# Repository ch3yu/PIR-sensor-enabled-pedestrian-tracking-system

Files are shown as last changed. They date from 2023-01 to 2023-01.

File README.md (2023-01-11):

# PIR-sensor-enabled-pedestrian-tracking-system

### **:closed_book:Introduction**

Passive infrared (PIR) sensors are motion sensors that detect IR stimuli emitted by heating bodies and convert them into electrical outputs. They are used in a variety of applications, such as home automation, surveillance systems, and human trajectory analysis since they are low-cost, reliable and anonymous compared to other sensors like camera and Bluetooth tags, which are relatively expensive and privacy-invasive. 

PIR sensors are categorized into digital and analog sensors, and they both have their advantages and disadvantages.  Digital PIR sensors are the more common option that outputs 1 when motions are detected and 0 otherwise. A considerable number of applications that leverage their binary outputs since they require less effort to process and off-the-shelf digital PIR sensors are easy to access due to its prevalence. However, the digital characteristics also narrow the information availability to users – digital PIR sensors can reflect nothing more than the presence of motions. Whereas its analog counterpart can not only sense motions, but also provide direction, velocity, and distance of pedestrians relative to the sensor by giving different outputs, which requires multiple digital PIR sensors to work synergistically to collect the same information. As informative as analog PIR sensors can be, they require additional amplification since the raw analog outputs are not prominent enough to be observed and processed directly by microcontrollers. Despite the implication of an additional amplifier, we still prefer analog PIR sensors since they are not only more informative, but they are also more energy-efficient in contrast to the digital counterpart when requiring the same capabilities.

To enable more people to benefit from analog PIR sensors, we designed a sensing node that pivots around an analog PIR sensor and included a GPS, SD card module, Arduino UNO, a divided cone, and a power supply system. In the sensing node, we have a plastic circuit board (PCB) that harbors the amplifier for the analog output, SD card module for data storage, and GPS capability to document information captured by the PIR sensor chronologically. The PCB also serves as a shield that sits atop an Arduino UNO so that users can expand the functionalities of the PCB of their own accord. Additionally, we also devised a cone with a divider that increases the sensitivity of the sensor. All components reside in a water-proof enclosure and are powered by a battery, which is sustainably charged by a solar panel.

In this GitHub page, we have a sensor node building manual, bill of materials, design files, and code in different branches. Please refer to the index section for further information for the purposes of each file.

### **:scroll:Index**

- Pedestrian tracking system sensing node assembling manual: A step-by-step instruction that goes through the process of building a sensing node pivoting around an analog PIR sensor.
- Bill of materials: A list that includes all the materials needed to build a sensing node.
- Design files:
  - Pedestrian tracking system: A compressed folder that contains the Gerber files for the Arduino shield.
  - Cone and tube stl files: The stl files that can be sent to a 3D printing manufacturer to print out the cone and the tube.
- pedestrian_tracking_system_3: The code that operates to document direction of travel of passengers.

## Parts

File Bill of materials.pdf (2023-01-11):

Category | Item | Part Number | Quantity | Vendor | Note
Electronics | PIR sensor | D203B | 1 | Ebay
| SD card module | Daier 1.29 | 1 | Amazon
| SD card | B087JCL881 | 1 | Amazon
| GPS receiver | GPS-13670 | 1 | Sparkfun
| GPS jumper wires | PRT-10361 | 1 | Sparkfun
| Arduino UNO | A000066 | 1 | Amazon
| Op-amp | LF412ACN/NOPB | 2 | Digikey
| Resistor - 10k | CF14JT10K0TR-ND | 3 | Digikey
| Resistor - 100k | CF18JT100KTR-ND | 1 | Digikey
| Resistor - 1M | VR68J1.0MCT-ND | 3 | Digikey
| Resistor - 3.3M | CF14JT3M30TR-ND | 1 | Digikey
| Capacitor - 0.1u | 493-12784-1-ND | 2 | Digikey
| Capacitor - 10u | 493-7383-1-ND | 3 | Digikey
| Male header | PBC36SADN | 1 | Digikey
| Two-position female header | PPTC021LFBN-RC | 1 | Digikey
| Three-position female header | PPPC031LFBN-RC | 1 | Digikey
| Two-position terminal block | B08B3JP9QZ | 1 | Amazon
| Three-position terminal block | B082QZ8Q3X | 1 | Amazon
Enclosure | Waterproof box | WQ-55-02 | 1 | Polycase
| Pole mount kit for box | PK-083 | 1 | Polycase
| Screws | SCREWS-032-50 | 1 | Polycase
Power Supply | Battery | PS-1280-F1 | 1 | TNR technical
| Solar controller | SS-6L-12V | 1 | Morning Star
| Female connection receptacle | 298-10278-ND | 2 | Digikey | Used to connect the 12 AWG chord to the terminals of the battery
| 12 AWG chords | B074GG48F2 | 3 | Amazon
| Solar panel | HY010-12M | 1 | Acopower
| Pole mount kit for solar panel | SLB-0120 | 1 | Solarland
| Connection receptacle | 889-1000-ND | 1 | Digikey | Used to create water-proof connection for the solar panel and the enclosure
| Connection plug | 889-1012-ND | 1 | Digikey
| Nickel crimp | 889-1049-1-ND | 1 | Digikey
| Cable | 1897CSL002-ND | 1 | Digikey
| Cable gland | AIO-CSM12-ND | 1 | Digikey
Miscellaneous | Jumper wires | 1988-1169-ND | 5 | Digikey
| Zip ties | B08TBM621K | 1 | Amazon
| Electrical tape | 13717044 | 1 | Target
| Gorilla super glue | 75575255 | 1 | Target
| Solder machine | MX 500S | 1 | Metcal
| Solder wire | 468-480 | 1 | Jensen
| Drill | B09SN6Y6TS | 1 | Amazon | The drill bit has 0.5" diameter

Note: This bill of materials is listed for one sensing node.

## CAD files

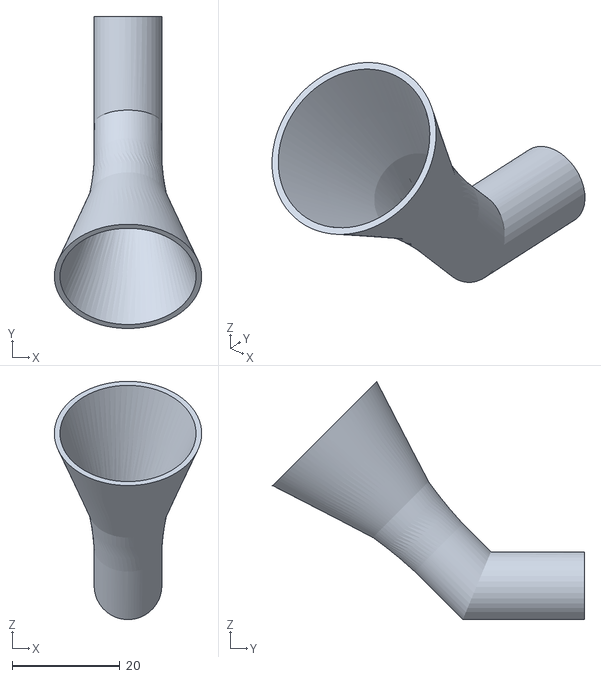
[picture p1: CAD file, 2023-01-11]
Design files/Tube.STL
27.4 x 58.0 x 44.3

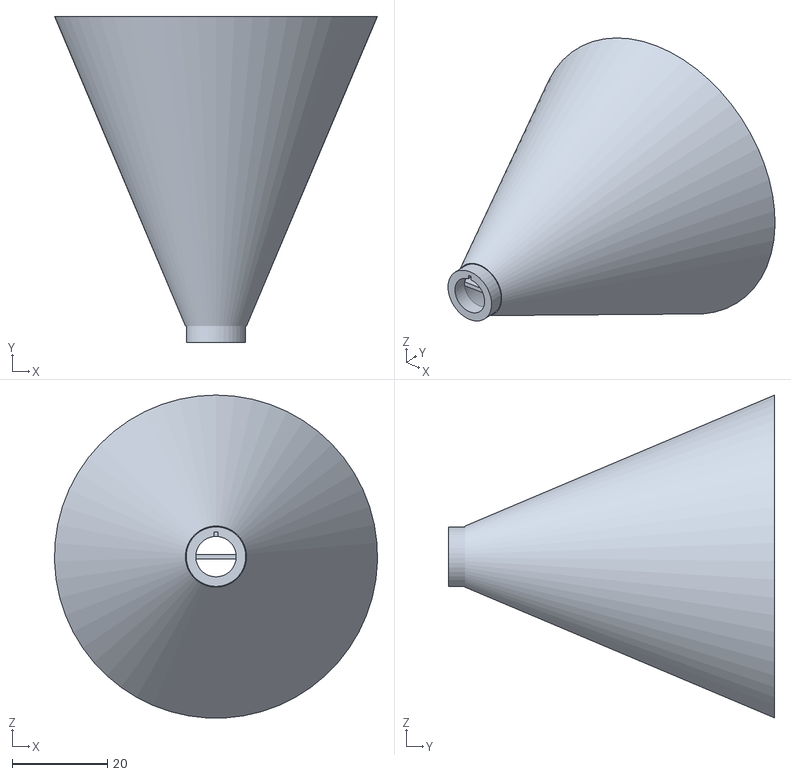
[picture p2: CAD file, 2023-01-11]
Design files/Cone.STL
67.8 x 68.5 x 67.8

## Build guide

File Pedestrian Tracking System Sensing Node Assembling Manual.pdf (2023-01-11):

# Pedestrian Tracking System Sensing Node Assembling Manual

## Author: Cheyu Lin

## Contact: cheyul@andrew.cmu.edu

Index

Introduction

Passive infrared (PIR) sensors are motion sensors that detect IR stimuli emitted by heating bodies and convert them into electrical outputs. They are used in a variety of applications, such as home automation, surveillance systems, and human trajectory analysis since they are low-cost, reliable and anonymous compared to other sensors like camera and Bluetooth tags, which are relatively expensive and privacy-invasive.

PIR sensors are categorized into digital and analog sensors, and they both have their advantages and disadvantages. Digital PIR sensors are the more common option that outputs 1 when motions are detected and 0 otherwise. A considerable number of applications leverage their binary nature since binary outputs require less effort to process and off-the-shelf digital PIR sensors are easy to access due to its prevalence. However, the digital characteristics also narrow the information availablility to users – digital PIR sensors can reflect nothing more than the presence of motions. Whereas its analog counterpart can not only sense motions, but also provide direction, velocity, and distance of pedestrians relative to the sensor by giving different outputs, which requires multiple digital PIR sensors to work synergistically to collect the same information. As informative as analog PIR sensors can be, they require additional amplification since the raw analog outputs are not prominent enough to be observed and processed directly by microcontrollers. Despite the implication of an additional amplifier, we still prefer analog PIR sensors since they are not only more informative, but they are also more energy-efficient in contrast to the digital counterpart when requiring the same capabilities.

To enable more people to benefit from analog PIR sensors, we designed a sensing node that pivots around an analog PIR sensor and included a GPS, SD card module, Arduino UNO, a divided cone, and a power supply system. In the sensing node, we have a plastic circuit board (PCB) that harbors the amplifier for the analog output, SD card module for data storage, and GPS capability to document information captured by the PIR sensor chronologically. The PCB also serves as a shield that sits atop an Arduino UNO so that users can expand the functionalities of the sensing node of their own accord. Additionally, we also devised a divided cone that increases the sensitivity of the sensor. All components reside in a water-proof enclosure and are powered by a battery, which is sustainably charged by a solar panel.

In this manual, we provide step-by-step instructions pictorially to construct the sensing node, which entailstools required to build the sensing node, the process of soldering components onto the PCB, assembling the cone, creating water-proof connections that are exposed, and putting everything together. To download design files for the PCB and the cone, code, and bill of materials, please consult the GitHub page.

Tools Required to Build the Sensing Node

Fig. 1 and 2 show all the tools needed to assemble the sensing node.

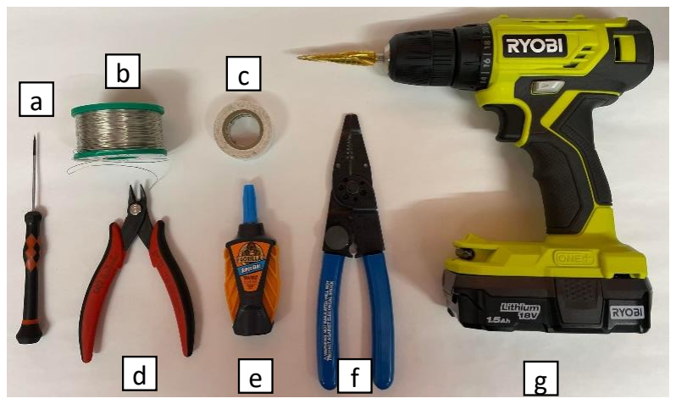
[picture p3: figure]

Fig. 1. (a) Flat-head screwdriver (b) solder wire
(c) electrical tape (d) wire cutter (e) super glue
(f) wire strip (g) driller

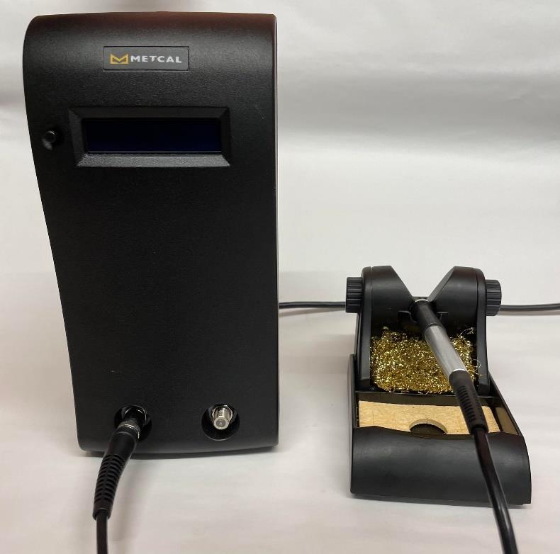
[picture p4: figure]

Fig. 2. Solder station and solder iron

PCB Schematic

In this section, we have the schematic of the Arduino shield that is comprised of external power supply, Arduino power supply, GPS and SD card module connections, and PIR signal amplifier in Fig. 2. The external power supply is connected to a 12-V battery to power Arduino, which subsequently powers the operation of the rest of the circuit through the 5-V pin in the Arduino power supply. GPS and SD card module are connected to the shield through “JP” labelled solder pads. As for the PIR signal amplifier, it processes the raw PIR signal by sending the signal through a non-inverting and an inverting band-pass filter, made up of operational amplifiers, resistors, and capacitors, and feeding the output to Arduino’s analog pin A1. As a side note, “JP” labelled solder pads named “Arduino spare pins” are for adding external components according to user’s needs. For instance, if an LED light is required, one can connect it to pin 5 in JP6, and control it through Arduino’s digital pin 5.

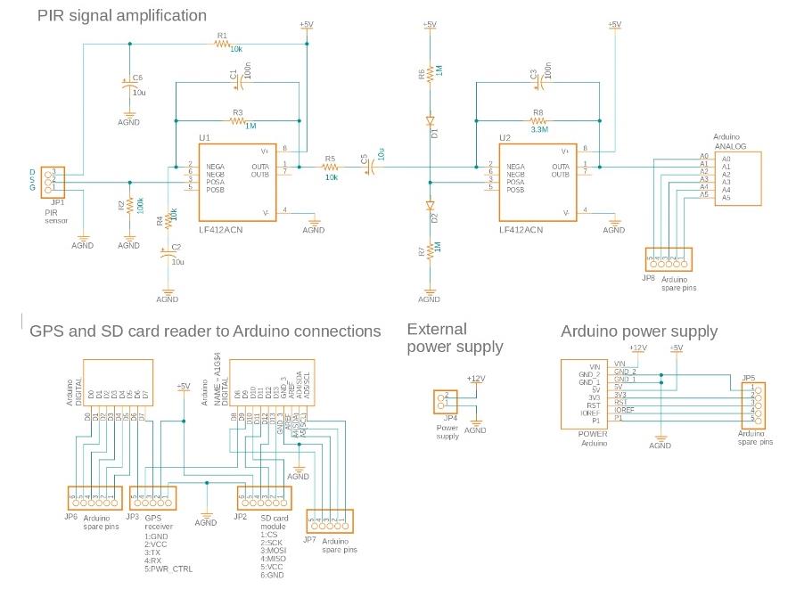
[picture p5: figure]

Fig. 2. Schematic of the Arduino shield that includes amplifier for raw PIR signal, GPS, and SD card module.

Soldering Arduino Shield

1. Download Gerber files from GitHub page under main -> Design files -> Pedestrian tracking system.zip. Print the PCB from the PCB factory of user’s preference.
2. Purchase components listed in the bill of materials (also accessible in GitHub page). If user has your own preferences, please ensure that components bought would line up with solder pads on the PCB.
3. Identify the front and back sides in Fig. 3 before soldering since some components belong to the front side and others belong the back side.

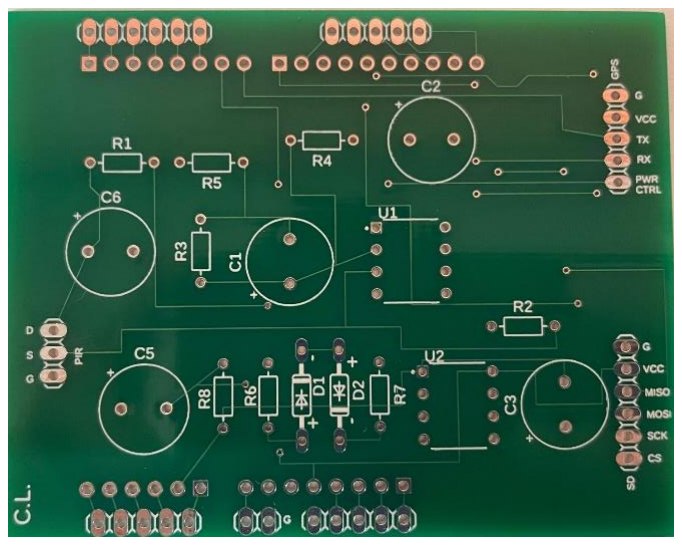
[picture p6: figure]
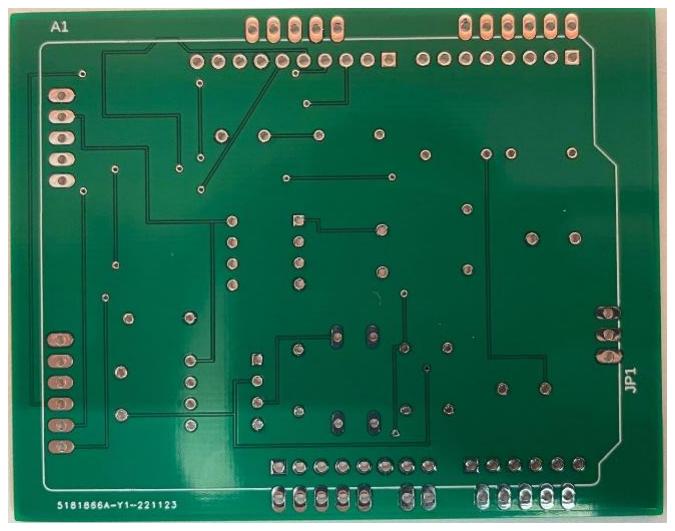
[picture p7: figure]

(a) (b)
Fig. 3. (a) The front side of the PCB has resistors, capacitors, diodes, and op-amps labelled as “R”, “C”, “D”, and “U” respectively. The “+” signs indicate positive polarity. (b) The back side of the PCB.
4. Solder the SD card module onto the back of the PCB by connecting module’s pins to their corresponding places as shown in Fig. 4.
5. Solder the short end of male headers onto the front side of the PCB as in Fig. 5. One tip is to insert the long end of the headers into an Arduino and place the PCB on top while soldering to ensure headers are not lopsided. A caveat is that the long end of headers must be long enough to leave a clearance when fitting the PCB onto Arduino. See Fig 13 for visual explanation.
6. Solder op-amps onto the front side of the PCB with the dented pit on the op-amp aligning the white dot on the PCB as shown in Fig. 6.

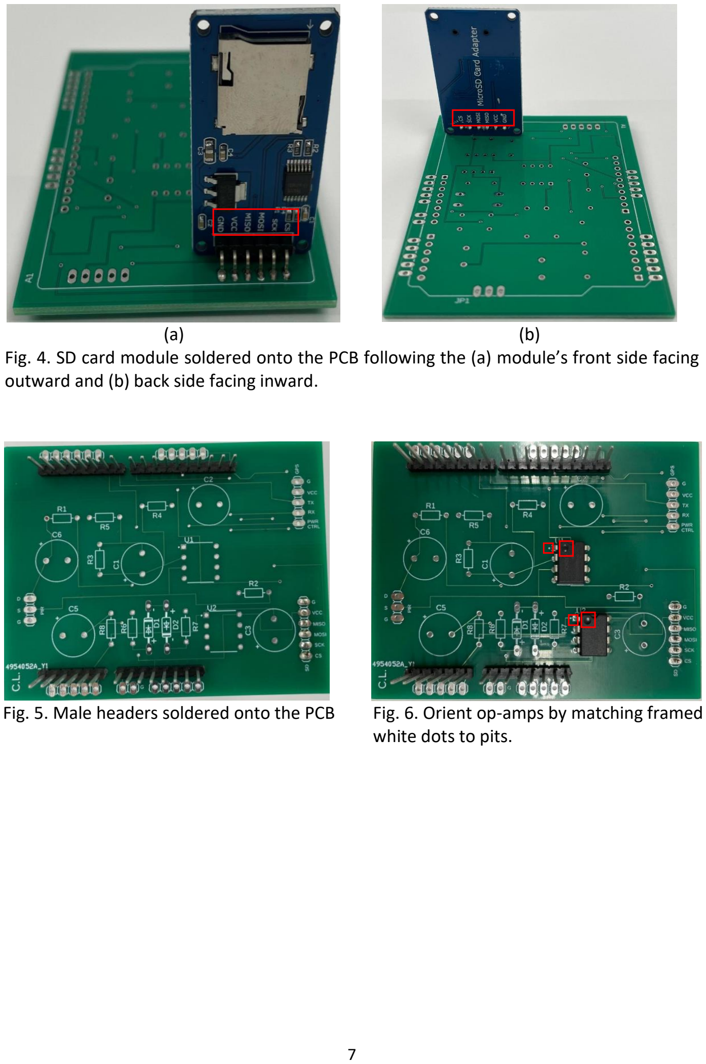
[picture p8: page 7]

(a) (b)
Fig. 4. SD card module soldered onto the PCB following the (a) module’s front side facing outward and (b) back side facing inward.

Fig. 5. Male headers soldered onto the PCB Fig. 6. Orient op-amps by matching framed white dots to pits.

7. Resistors are on the back side of the PCB. Solder 10k resistors to R1, R4, and R5; 100k to R2; 1M to R3, R6, and R7; 3.3M to R8. See Fig. 3 and 7 for reference.

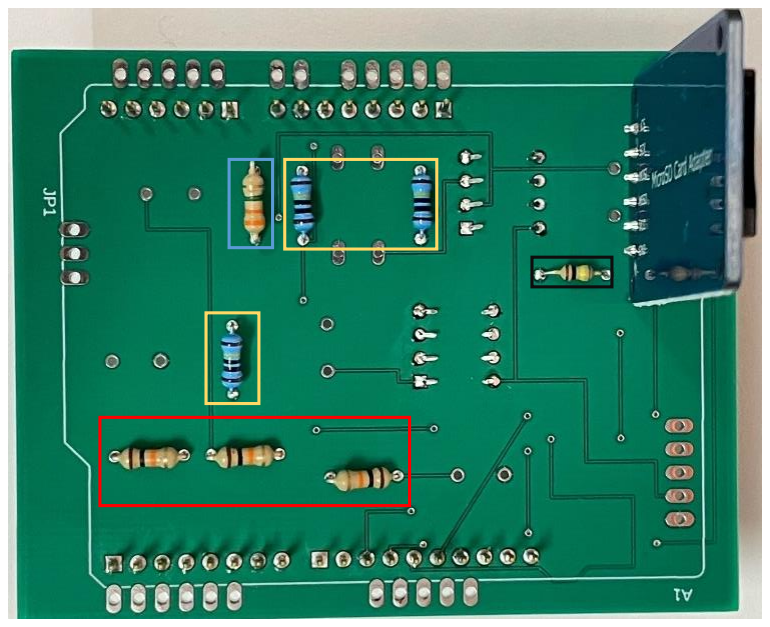
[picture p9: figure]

Fig. 7. Resistors are framed with different colors to indicate different resistances. 10k resistors are red. 100k resistor is black. 1M resistors are boxed yellow. 3.3M resistor is boxed blue.

8. Connect polarized capacitors on the back of the PCB with the white stripe on the capacitor lining up with the negative sign on the PCB. Please refer to Fig. 3 and 8 to identify the polarities of capacitors and the corresponding solder pads on the PCB.

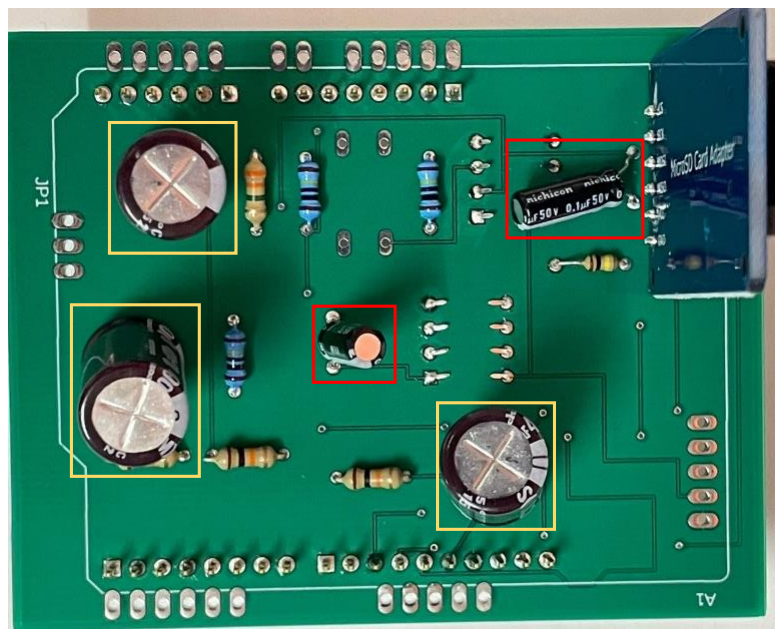
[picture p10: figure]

Fig. 8. 100n capacitors are boxed red, whereas 10u capacitors are boxed yellow.

9. Solder female headers onto the back of the PCB as shown in Fig. 9.

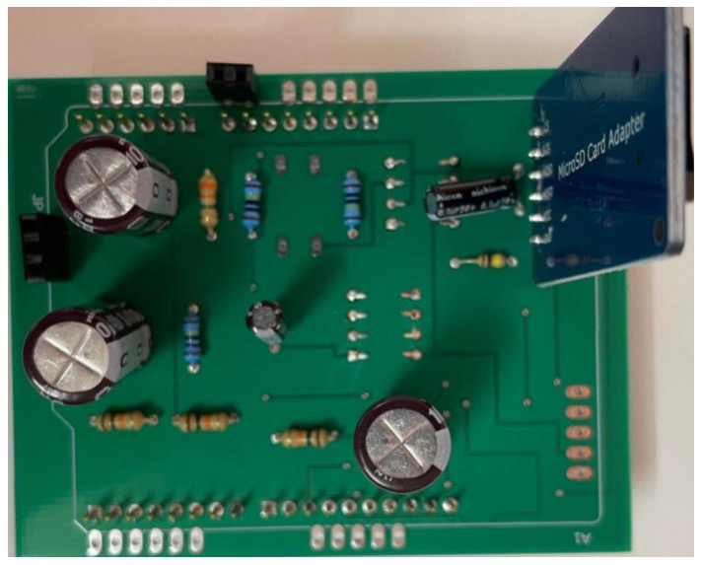
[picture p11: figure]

Fig. 9. The two-position header is for power supply, and the three-position header is for PIR sensor.

10. Solder diodes onto the back side of the PCB with the black striped end connecting to the negative pin on the PCB. Please refer to Fig. 3 and 10 to identify the polarities of diodes and the PCB.

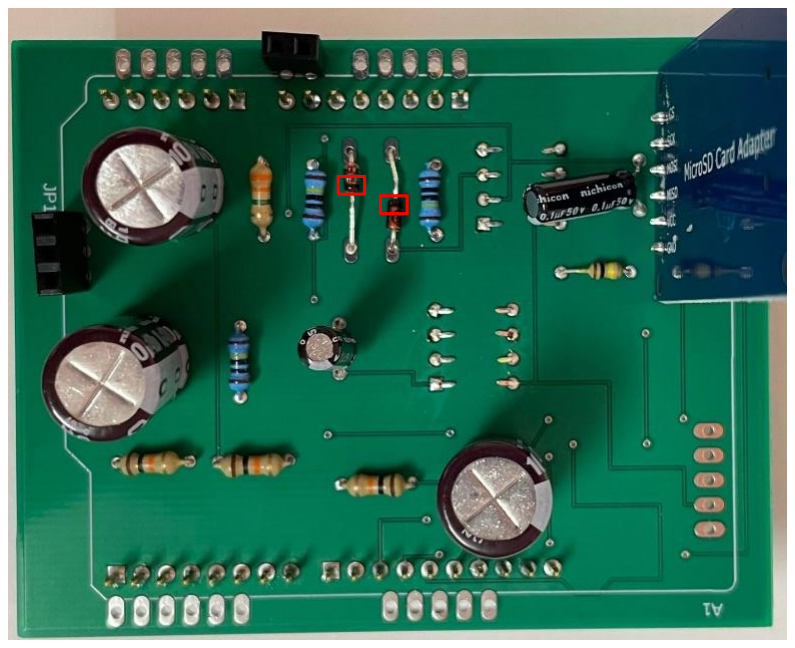
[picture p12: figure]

Fig. 10. The black stripe that indicates negative polarity of diodes are framed in red boxes.

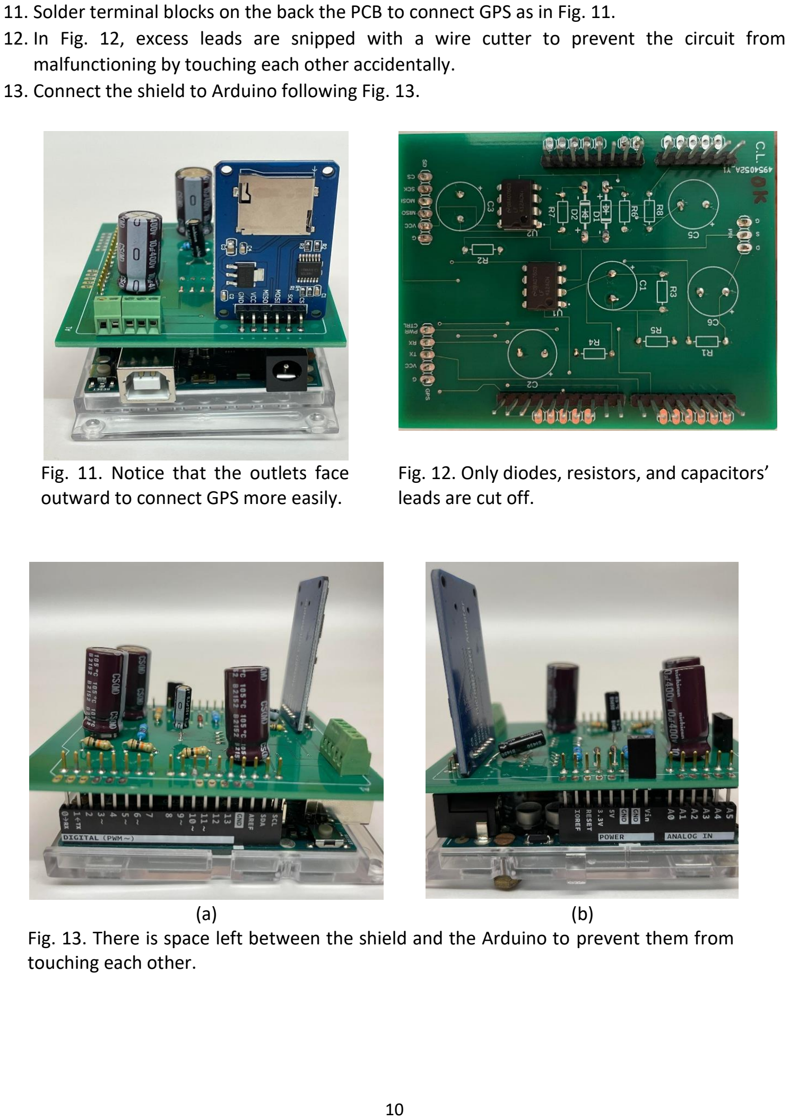
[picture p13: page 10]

11. Solder terminal blocks on the back the PCB to connect GPS as in Fig. 11.
12. In Fig. 12, excess leads are snipped with a wire cutter to prevent the circuit from malfunctioning by touching each other accidentally.
13. Connect the shield to Arduino following Fig. 13.

Fig. 11. Notice that the outlets face outward to connect GPS more easily.

Fig. 12. Only diodes, resistors, and capacitors’ leads are cut off.

(a) (b)
Fig. 13. There is space left between the shield and the Arduino to prevent them from touching each other.

14. Connect the GPS to the terminal blocks and insert a micros SD card into the SD card module.
15. See Fig. 15 for the completed result.

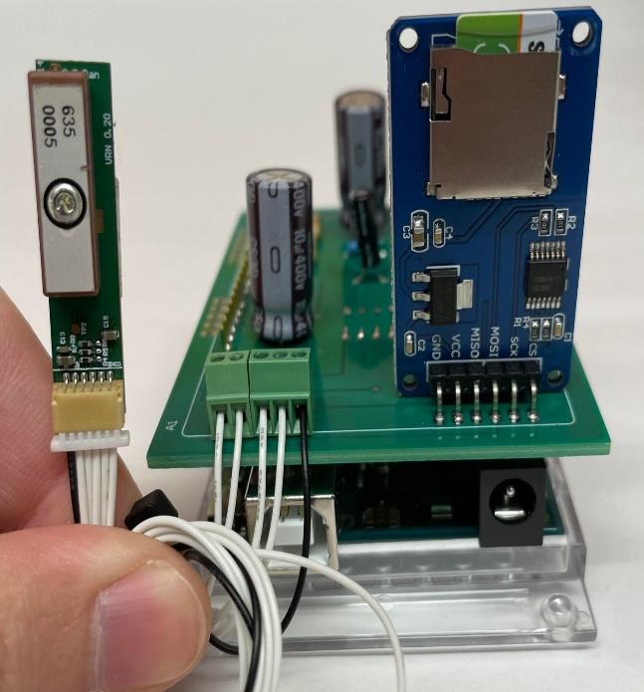
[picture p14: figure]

Fig. 14. Insert wires into the terminal blocks and tighten them to connect GPS.

Fig. 15. Completed! Be proud!

Assembling PIR Cone and Tube
1. Download stl files from GitHub page under main -> Design files -> Cone.STL and Tube.STL. Print the cone and tube from a 3D printing machine. The material we used is acrylonitrile butadiene styrene (ABS) filament.
2. Please refer to Fig. 16 for different perspectives of the PIR cone.

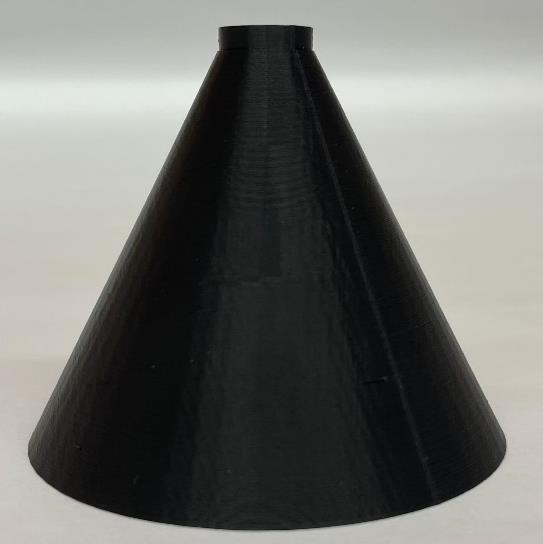
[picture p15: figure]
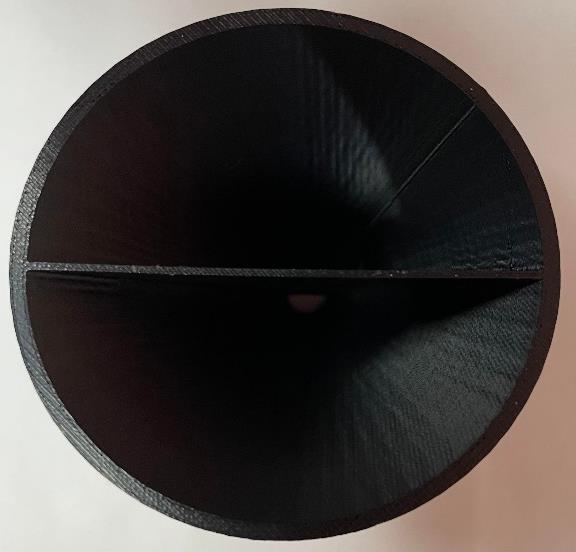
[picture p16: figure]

(a) (b)
Fig. 16. (a) Side view and (b) bottom view and the divider of the cone.
3. Insert the PIR sensor into the cone with the protuberance oriented vertically with the divider in the cone. Apply a layer of super glue over the PIR sensor to attach it to the cone. Connect jumper wires to the sensor and crimp the headers to tighten the connections. See Fig. 17.
4. Cover the tube over and glue it to the cone with super glue as in Fig. 18.

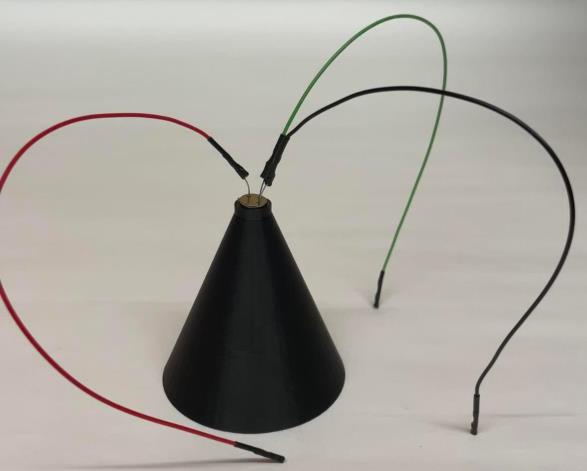
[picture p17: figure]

Fig. 17. The wires here are color-coded, where red is connected to drain, green to source, and black to ground.

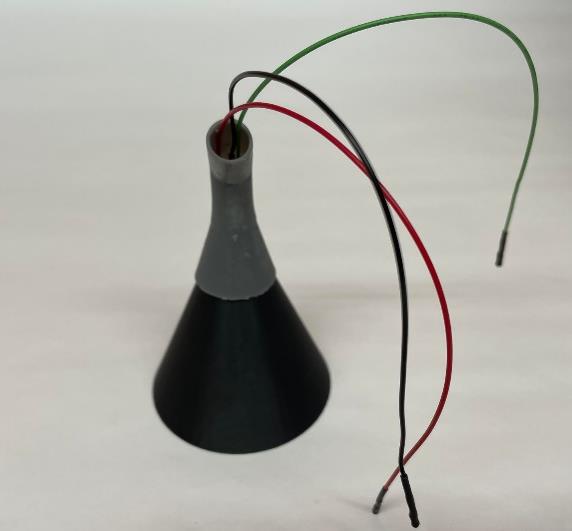
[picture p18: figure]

Fig. 18. Finished product!

Putting Everything Together

1. Peel and strip wires using a wire cutter and a wire strip as shown in Fig. 16.

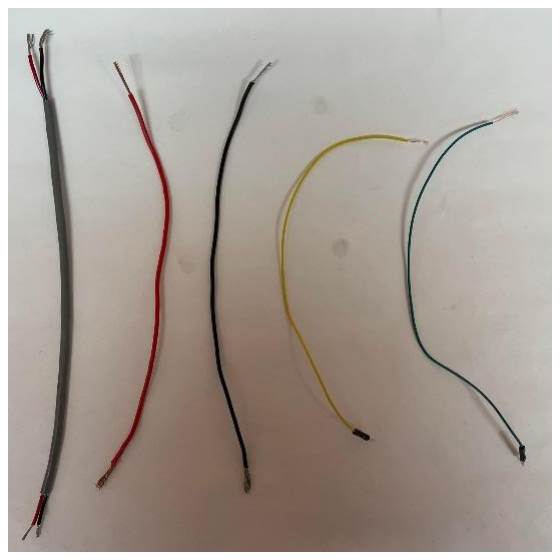
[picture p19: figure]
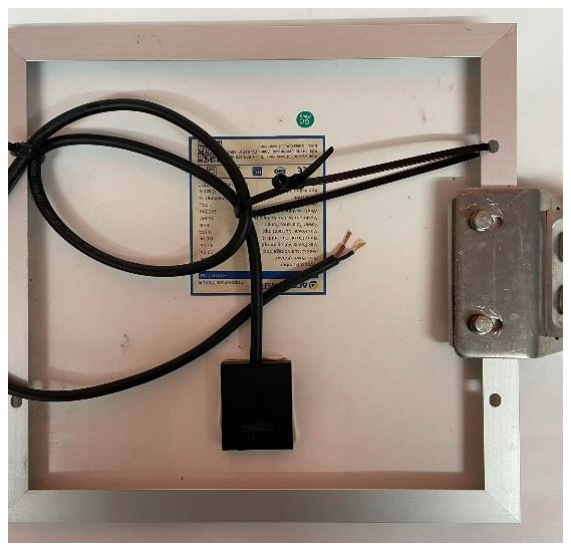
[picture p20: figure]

(a) (b)
Fig. 16. (a) From left to right we have a gray cable used to connect the solar controller to solar panel, two 12-AWG cables to connect solar controller to the battery, and two jumper wires to connect the solar controller to the shield. (b) Peeled and stripped wires behind solar panel.
2. Drill a hole of 0.5-inch diameter and pull the stripped gray cable in Fig. 19 (a) through the cable gland and feed it through the hole into the box as shown in Fig 20.

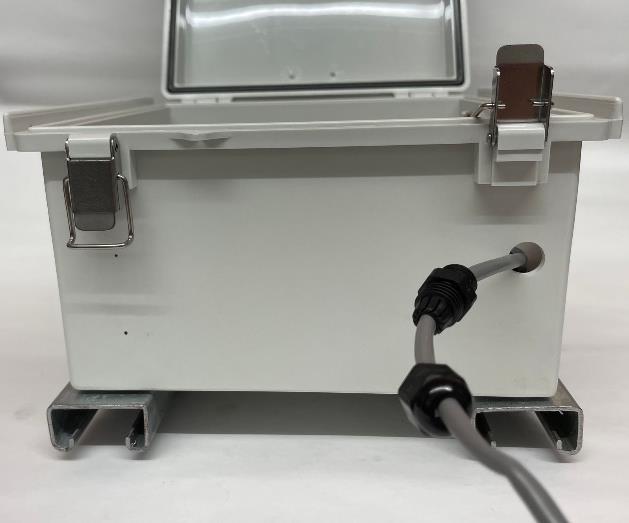
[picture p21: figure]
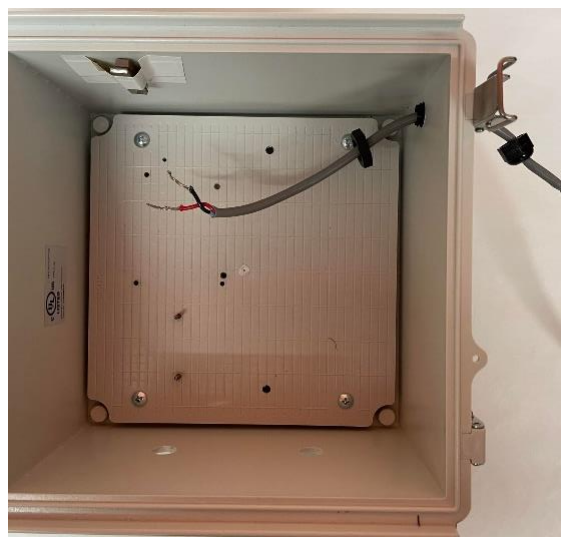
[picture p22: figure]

(a) (b)
Fig. 20. (a) Side view of the cable pulled through cable gland and into the box. (b) Top view of the cable. The cable gland is unscrewed into three pieces to demonstrate the relative position of each piece. Please tighten them after the cable is pulled into the box.

3. In Fig. 21, the two wires in the middle are crimped in female connection receptacles. Whereas the two outer cables are clenched by nickel crimps and pushed into connection receptacle and connection plug respectively until clicked.
4. Connect the wires to solar controller by wrapping the metal around the screws (as demonstrated with the left most cable in Fig. 22) and tighten them.

Fig. 21. Two outer cables should be held tight by nickel crimps that are
left | out | for | demonstration
purposes before pushing into the receptacle and the plug.

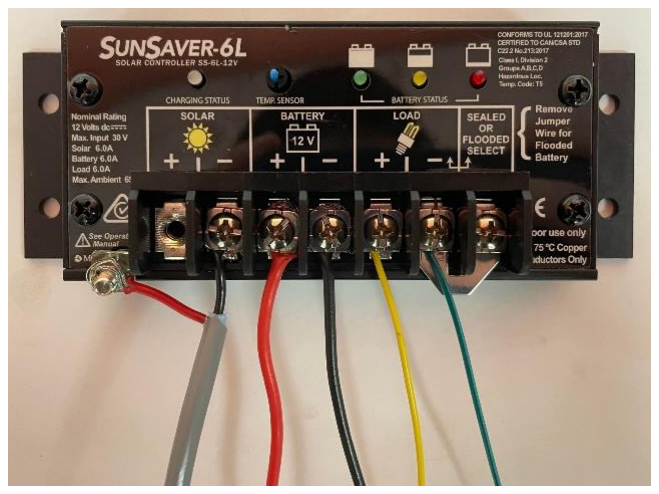
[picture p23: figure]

Fig. 22. Please remember to tighten the unscrewed wire into the solar controller.

5. Drill another 0.5-inch diameter hole at the bottom of the box and insert the PIR cone made in the previous section as demonstrated in Fig. 23.

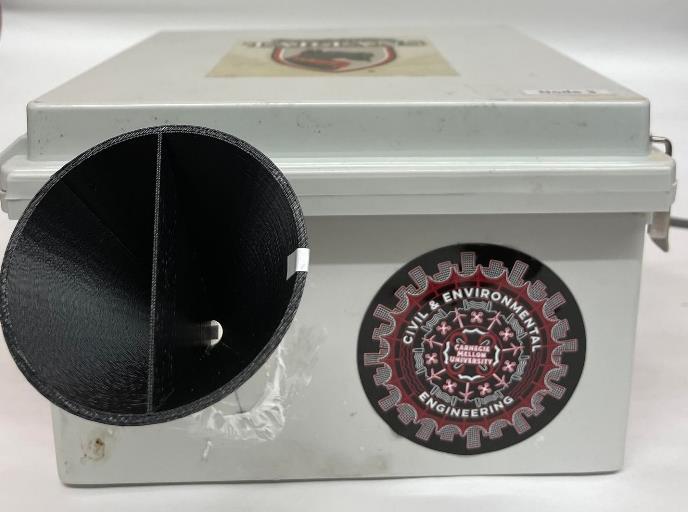
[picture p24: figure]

Fig. 23. The white label on the cone is used to mark orientation of the PIR sensor, which corresponds to the side of the PIR sensor without the protuberance.

6. Place the solar controller, battery, and Arduino into the box and connect everything!
7. Connect the solar controller with the solar panel!

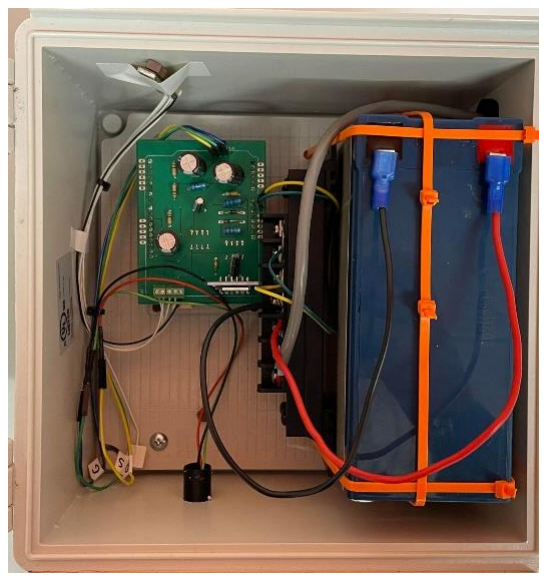
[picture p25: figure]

Fig. 24. Components can be fixed to the box using zip ties and screws to
prevent | wobbling | during
transportation.

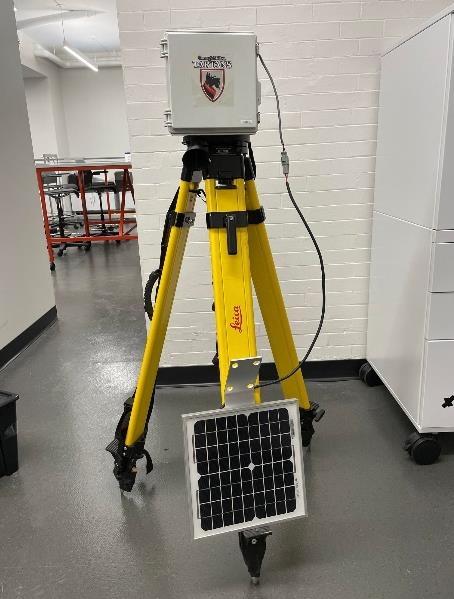
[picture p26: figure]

Fig. 25. Great job!

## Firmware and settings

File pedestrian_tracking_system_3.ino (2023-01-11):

/*****************************************************************************************************************************
 * pedestrian_tracking_system_3 is for the second appointment for the pedestrain tracking system implemented in Mellon Park.
 * It detects pedestrians' travel directions by leveraging the property of an analog PIR sensor that the output waveforms are 
 * different with respect to different travel directions.
 * 
 * Arduino expects analog signal from a PIR sensor and logs the time information and travel direction onto a SD card once it
 * senses passings of pedestrians.
 * 
 * Author: Cheyu Lin
 *****************************************************************************************************************************/

// Include libraries for GPS, time management, and SD card modules
#include <SoftwareSerial.h>
#include <TimeLib.h>
#include <Timezone.h>
#include <SD.h>
#include <SPI.h>

# define baud 9600   // Baud rate for serial input and output
# define warmup_pir 120000  // Warm up time for PIR sensor - 120000 milliseconds
# define mapping_bit 1024  // mapping_bit and mapping_volt are for ADC conversions
# define mapping_volt 5
# define daylight_saving_2am 2  // The hour when daylight saving happens
# define time_diff_4hrs -240
# define time_diff_5hrs -300
# define delay_2sec 2000  // 2000 milliseconds
# define delay_10sec 10000  // 10000 milliseconds

// Instance declaration
SoftwareSerial ss(7, 8);
File myFile;
TimeChangeRule usEDT = {"EDT", Second, Sun, Mar, daylight_saving_2am, time_diff_4hrs};  //UTC - 4 hours (240 mins)
TimeChangeRule usEST = {"EST", First, Sun, Nov, daylight_saving_2am, time_diff_5hrs};   //UTC - 5 hours (300 mins)
Timezone usEastern(usEDT, usEST);


// GPIO pin assignment
int pir = A1;  // Reading analog signal from a PIR sensor
int gps_wake = 6;
int pinCS = 10;
int led1 = A2;
int led2 = A3;
int gps_signal = A4;

// Variable declaration
char pirPosition[2] = "L";
float threshold_high = 3.0;
float threshold_low = 2.0;
float input;
float val;
unsigned long time_window = 1000; // milliseconds
unsigned long dead_indicator = 0;  // the byte position in the SD card file to log time information to track the status of the battery
unsigned long dead_interval = 900;
unsigned long dead_timer = 0;
time_t eastern, utc;

int recalibrate_hr = 8;
int recalibrate_min = 0;
int recalibrate_sec1 = 0;
int recalibrate_sec2 = 2;


/*****************************************************************************************************************************
 * pir_struct is used to track the progression of a PIR wave.
 * 
 * Below are the explanation for different fields:
 *  time_first: Documents the time when the signal crosses either the high threshold (3 volts) or the low threshold (2 volts)
 *  time_second: Keeps being updated until a wave finishes.
 *  flag_trigger: Tracks the progression of a PIR wave.
 *  
 * With time_first and time_second, we can check the status of the PIR sensor. Under normal circumstances, a PIR wave finishes
 * within 1 second. If most signals take more than 1 second to end, it indicates a need to replace the current sensor.
 *****************************************************************************************************************************/
struct pir_struct{
  unsigned long time_first;
  unsigned long time_second;
  int flag_trigger;
};

// Initialize pir struct
pir_struct pir_trigger;


void setup() {
  Serial.begin(baud);
  ss.begin(baud);

  // Declare modes of all pins.
  pinMode(pir, INPUT);
  pinMode(gps_wake, OUTPUT);
  pinMode(pinCS, OUTPUT);
  pinMode(led1, OUTPUT);
  pinMode(led2, OUTPUT);
  pinMode(gps_signal, OUTPUT);

  // Capture time information
  getTime();

  // Check if SD card module is operating correctly
  if(SD.begin(pinCS)){
    Serial.println(F("SD card is ready to use."));
  }
  else{
    Serial.println(F("SD card initialization failed."));
  }

  // Initialize a pir_struct struct
  pir_trigger.flag_trigger = 0x0;
  pir_trigger.time_first = 0;
  pir_trigger.time_second = 0;

  // Open the the file in the SD card.
  myFile = SD.open("test.txt", O_RDWR | O_CREAT);
  // Check if file is opened sucessfully.
  if(myFile)
  {
    // Check if it is an empty file, namely new SD card.
    myFile.seek(myFile.size());
    if(!myFile.available())
    {
      Serial.println(F("No file in the SD card!"));
    }
    else
    {
      Serial.println(F("A file is found in the SD card!"));
    }
  }
  else
  {
    Serial.println(F("Error opening test.txt!"));
  }
  // Close the opened file to ensure data is physically stored in the SD card.
  myFile.close(); 
  
  logSD(1);
  logSD(2);

  delay(warmup_pir);
}

void loop() {
  // Recalirbrate at designated time every day
  eastern = changeTimeZone();
  if((hour(eastern) == recalibrate_hr) && (minute(eastern) == recalibrate_min) && (second(eastern) >= recalibrate_sec1) && (second(eastern) <= recalibrate_sec2)){
    getTime();
  }
  
  // Update the time stamp below "Start" every 15 minutes
  if((now() - dead_timer) >= dead_interval){
    dead_timer = now();
    logSD(2);
  }


/*****************************************************************************************************************************
 *            __                                           __
 * 3.0V___0x1/  \0x2__________________________________0X40/  \0X80________
 *          /    \                                       /    \
 * 2.5V----/      \      /-----------------------\      /      \----------
 *     ____________\    /_________________________\    /__________________
 * 2.0V          0x4\__/0x8                    0X10\__/0X20
 *                  
 *         <Left to right>                        <Right to left>   
 *         
 * When motions are detected, an analog PIR sensor produces different signals
 * depending on the motions, which are a wave offset by 2.5V with the wave crest
 * comes first if an heating body moves from left to right and a wave with a
 * preceding wave trough otherwise respectively. To differentiate the two directions,
 * we track the progression of a wave by tagging points that cross the 2V or 3V
 * threshold as in the graph above - a left to right travel will be recorded
 * only when a wave gets tagged with 0x1, 0x2, 0x4, and 0x8, and a right to left travel
 * will be documented only when a wave goes through 0x10, 0x20, 0x40, and 0x80
 * completely. A condition statement that quits the tracking if a wave stays at either
 * 0x2 or 0x20 over two seconds is set to ensure the code doesn't grow stagnant
 * halfway through a wave.
 *****************************************************************************************************************************/
  // Read analog PIR signal
  input = analogRead(pir);
  // ADC conversion
  val = input / mapping_bit * mapping_volt;

  // Check if two triggers span over 1 seconds
  if(pir_trigger.flag_trigger == 0x2 || pir_trigger.flag_trigger == 0x20)
  {
   pir_trigger.time_second = millis();
   if(pir_trigger.time_second > time_window + pir_trigger.time_first)
   {
    pir_trigger.time_first = 0;
    pir_trigger.time_second = 0;
    pir_trigger.flag_trigger = 0x0;
   }
  }
  
  // Trigger if pir gives voltage greater than 3 volts
  if(val >= threshold_high)
  {
    if(pir_trigger.flag_trigger == 0x0)
    {
      pir_trigger.flag_trigger = 0x1;
      pir_trigger.time_first = millis();
      pir_trigger.time_second = millis();
    }
    else if(pir_trigger.flag_trigger == 0x1) pir_trigger.flag_trigger = 0x2;
    else if(pir_trigger.flag_trigger == 0x20) pir_trigger.flag_trigger = 0x40;
    else if(pir_trigger.flag_trigger == 0x40) pir_trigger.flag_trigger = 0x80;
    else if(pir_trigger.flag_trigger == 0x80)
    {
      while(val >= threshold_high)
      {
        input = analogRead(pir);
        val = input / mapping_bit * mapping_volt;
      }
      pir_trigger.flag_trigger = 0x0;
      pir_trigger.time_first = 0;
      pir_trigger.time_second = 0;
      logSD(4);
      digitalWrite(led1, HIGH);
      delay(delay_2sec);
      digitalWrite(led1, LOW);
    }
  }
  
  // Trigger if pir gives voltage less than 2 volts
  else if(val < threshold_low)
  {
    if(pir_trigger.flag_trigger == 0x0)
    {
      pir_trigger.flag_trigger = 0x10;
      pir_trigger.time_first = millis();
      pir_trigger.time_second = millis();
    }
    else if(pir_trigger.flag_trigger == 0x10) pir_trigger.flag_trigger = 0x20;
    else if(pir_trigger.flag_trigger == 0x2) pir_trigger.flag_trigger = 0x4;
    else if(pir_trigger.flag_trigger == 0x4) pir_trigger.flag_trigger = 0x8;
    else if(pir_trigger.flag_trigger == 0x8)
    {
      while(val <= threshold_low)
      {
        input = analogRead(pir);
        val = input / mapping_bit * mapping_volt;
      }
      pir_trigger.flag_trigger = 0x0;
      pir_trigger.time_first = 0;
      pir_trigger.time_second = 0;
      logSD(3);
      digitalWrite(led2, HIGH);
      delay(delay_2sec);
      digitalWrite(led2, LOW);
    }    
  }
}


/*
 * Functions
 */
/*****************************************************************************************************************************
 * getTime is used to capture time information from the gps - GP635 and update the time in Arduino. Specifically, we extract 
 * GPRMC, which is one of the NMEA messages. 
 * 
 * First, we wait until the GPS information is valid by waiting till the status byte in GPRMC message becomes "A". We then extract
 * time and date by counting commas. Time information comes after the first comma, whereas date information follows the ninth comma.
 * 
 * @param void
 * @return void
 * *****************************************************************************************************************************/
void getTime(){
  static const unsigned int MAX_MESSAGE_LENGTH = 67;
  bool TIME_CHECK = false;
  // Ping gps to turn it on
  digitalWrite(gps_wake, HIGH);
  // Delay 10 seconds to get rid of gibberish
  // delay(delay_10sec);
  while(!TIME_CHECK){
    // Check to see if anything is available to in the serial receive buffer
    while(ss.available() > 0){
      // Create a place to hold the incoming message
      static char message[MAX_MESSAGE_LENGTH];
      static unsigned int message_pos = 0;

      // Read the next available byte in the serial reciver buffer
      char inByte = ss.read();

      // Message coming in (check not terminating character)
      if(inByte != '\n' && (message_pos < MAX_MESSAGE_LENGTH - 1)){
        // Add the coming byte to our message
        message[message_pos] = inByte;
        message_pos++;
      }
      // Full message received
      else{
        // Check if the full message is '$GPRMC,' or not
        if((message[0] == '$') && (message[1] == 'G') && (message[2] == 'P') && (message[3] == 'R') && (message[4] == 'M') && (message[5] == 'C') && (message[6] == ',')){
          Serial.println(message);
          // Check the validity of the data by looking at the status byte
          if(message[17] == 'A'){
            int message_cnt = 0;
            int comma_cnt = 0;
            int hr, mins, secs, yr, mth, dayy;

            // Convert GPS characters into numerical values
            while(message_cnt < MAX_MESSAGE_LENGTH){
              if(message[message_cnt] == ','){
                comma_cnt++;
              }
              if(comma_cnt == 1){
                message_cnt++;
                hr = (int(message[message_cnt++]) - 48) * 10;
                hr = hr + (int(message[message_cnt++]) - 48);
                mins = (int(message[message_cnt++]) - 48) * 10;
                mins = mins + (int(message[message_cnt++]) - 48);
                secs = (int(message[message_cnt++]) - 48) * 10;
                secs = secs + (int(message[message_cnt]) - 48);
                comma_cnt++;
              }
              if(comma_cnt == 10){
                message_cnt++;
                dayy = (int(message[message_cnt++]) - 48) * 10;
                dayy = dayy + (int(message[message_cnt++]) - 48);
                mth = (int(message[message_cnt++]) - 48) * 10;
                mth = mth + (int(message[message_cnt++]) - 48);
                yr = (int(message[message_cnt++]) - 48) * 10;
                yr = yr + (int(message[message_cnt]) - 48);
                comma_cnt++;
              }
              message_cnt++;
            }
            // Set system time
            setTime(hr, mins, secs, dayy, mth, yr);
            TIME_CHECK = true;
            Serial.print(F("Year: ")); Serial.println(yr);
            Serial.print(F("Month: ")); Serial.println(mth);
            Serial.print(F("Day: ")); Serial.println(dayy);
            Serial.print(F("Hour: ")); Serial.println(hr);
            Serial.print(F("Minute: ")); Serial.println(mins);
            Serial.print(F("Second: ")); Serial.println(secs);
            
            // Turn gps off
            digitalWrite(gps_signal, HIGH);
            digitalWrite(gps_wake, LOW);
            // Flush all the data in the serial buffer
            while(ss.available() > 0){
              ss.read();
            }
            // Set all the data in the message to '0'
            memset(message, '0', MAX_MESSAGE_LENGTH);
          }
        }
        message_pos = 0;
      }
    }
  }
}

/*****************************************************************************************************************************
 * changeTimeZone changes the time zone from UTC+0 to UTC-5 (or UTC-4 during daylight saving). 
 * 
 * @param void
 * @return void
 * *****************************************************************************************************************************/
time_t changeTimeZone(){
 utc = now();
 return usEastern.toLocal(utc);
}

/*****************************************************************************************************************************
 * logSD logs data onto the file in the SD card depending on the input option:
 *  Option 1: Write "Start" at the end of each file every time Arduino is rebooted.
 *  Option 2: Write time below the latest "Start" and update it every 15 mins to document battery status. With this functionailty, 
 *            we can determine the time when the battery was out - it would be within 15 mins of the latest updated time. Additionally, 
 *            we can deduce the down time of the battery by comparing two times.
 *  Option 3: Log the time and direction of a pedestrian traveling from right to left.
 *  Option 4: Log the time and direction of a pedestrian traveling from left to right.
 * 
 * @param void
 * @return void
 * *****************************************************************************************************************************/
void logSD(int option){
  eastern = changeTimeZone();
  myFile = SD.open("test.txt", O_RDWR | O_CREAT);
  if(myFile){
    myFile.seek(myFile.size()); 
    if(option == 1){
      myFile.write("START\n");
      dead_indicator = myFile.size();
      Serial.println(F("Start."));
    }
    else if(option == 2){
      myFile.seek(dead_indicator);
      char str_time[25];
      sprintf(str_time, "%02d,%02d,%04d,%02d,%02d,%02d\n", month(eastern), day(eastern) , year(eastern), hour(eastern) ,minute(eastern), second(eastern));
      myFile.write(str_time);
      Serial.println(str_time);
    }
    else if(option == 3){
      myFile.seek(myFile.size());
      strcpy(pirPosition, "L");
      char str[25];
      sprintf(str, "%s,%02d,%02d,%04d,%02d,%02d,%02d\n", pirPosition, month(eastern), day(eastern), year(eastern), hour(eastern), minute(eastern), second(eastern));
      myFile.write(str);
      Serial.println(str);
    }
    else if(option == 4){
      myFile.seek(myFile.size());
      strcpy(pirPosition, "R");
      char str[25];
      sprintf(str, "%s,%02d,%02d,%04d,%02d,%02d,%02d\n", pirPosition, month(eastern), day(eastern), year(eastern), hour(eastern), minute(eastern), second(eastern));
      myFile.write(str);
      Serial.println(str);
    }
  }
  else{
    Serial.println(F("Error opening test.txt."));
  }
  // Close the opened file to ensure data is physically stored in the SD card
  myFile.close();
}
